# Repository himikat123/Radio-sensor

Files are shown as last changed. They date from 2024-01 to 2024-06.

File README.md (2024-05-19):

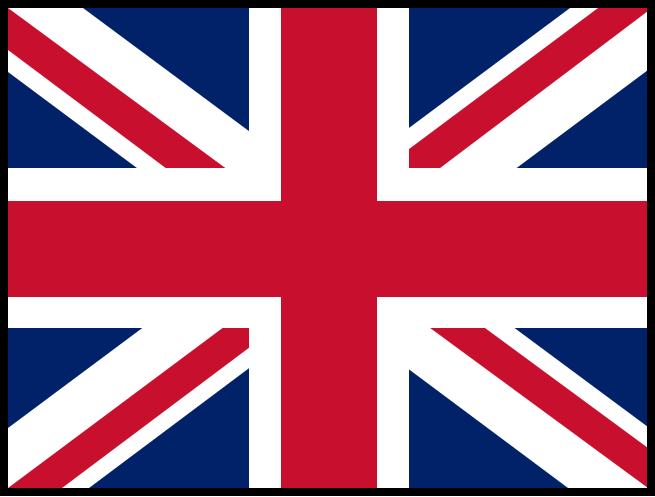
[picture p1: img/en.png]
Read this in english

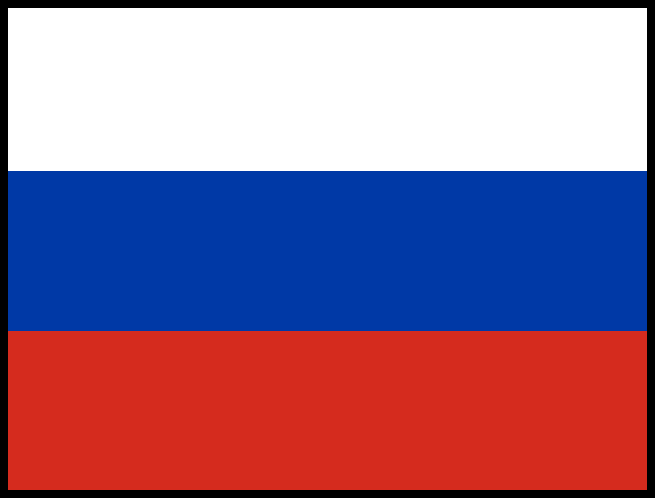
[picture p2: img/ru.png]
Читать на русском


# Radio-sensor

The radio-sensor is designed to work with the <a href="https://github.com/himikat123/Weather-monitor-BIM32">Weather Monitor BIM32.</a> It can work indoors or outdoors. Powered by three AAAA batteries (LR61). Also, the sensor can be powered from a Li-Ion battery, but it is preferable to use batteries, since batteries are not afraid of outdoor frost. 

Currently the radio-sensor supports the following sensors:
  * BME280 - temperature, humidity and atmospheric pressure sensor
  * SHT21 - temperature and humidity sensor
  * DS18B20 - temperature sensor (four such sensors can be connected at once)
  * MAX44009 - ambient light sensor
  * BH1750 - ambient light sensor
  * PZEM-004t - electricity meter (voltage, current, power, energy consumption, network frequency)
  * SenseAir S8 - CO2 sensor

Of course, you don’t need to connect everything from this list, but only those sensors that you need.

As an option, you can add a 4-digit, 7-segment display to the TM1637. Only the temperature can be displayed on the display, from only one temperature sensor. This is an experimental feature, I may remove it in the future.

The radio sensor is based on the Atmega328p microcontroller and the HC-12 radio module. This radio module operates at a frequency from 433.4 to 473.0 MHz and promises an information transmission range of up to 1800 meters.

## Radio-sensor schematic diagramm
The **Radio-sensor** itself can be assembled on the **Arduino Nano** module, or any other module built on the **atmega328p**. In this case, the circuit, assembly and flashing of the **Radio-sensor** will be as simple as possible, but in this form you can forget about the autonomous power supply of the sensor.

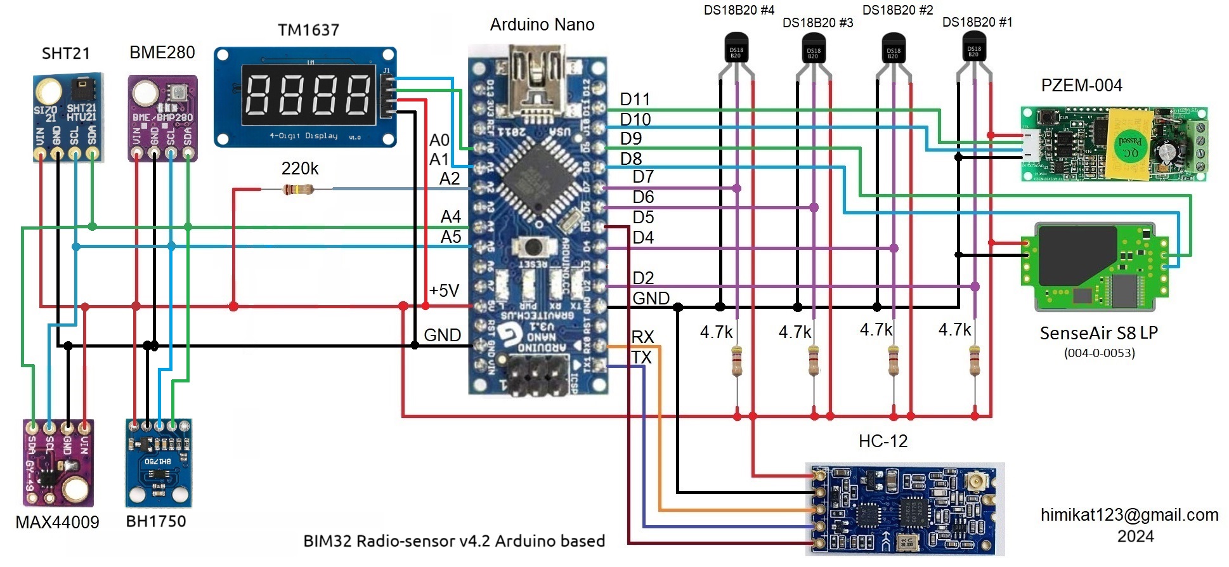
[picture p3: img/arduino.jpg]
weather monitor BIM32 radio-sensor arduino based


Or you can go a more complicated way, assemble the **Radio-sensor** from *SMD-components* and flash it with a programmer. In this case, the **Radio-sensor** will be able to live from three AA batteries for almost a year.

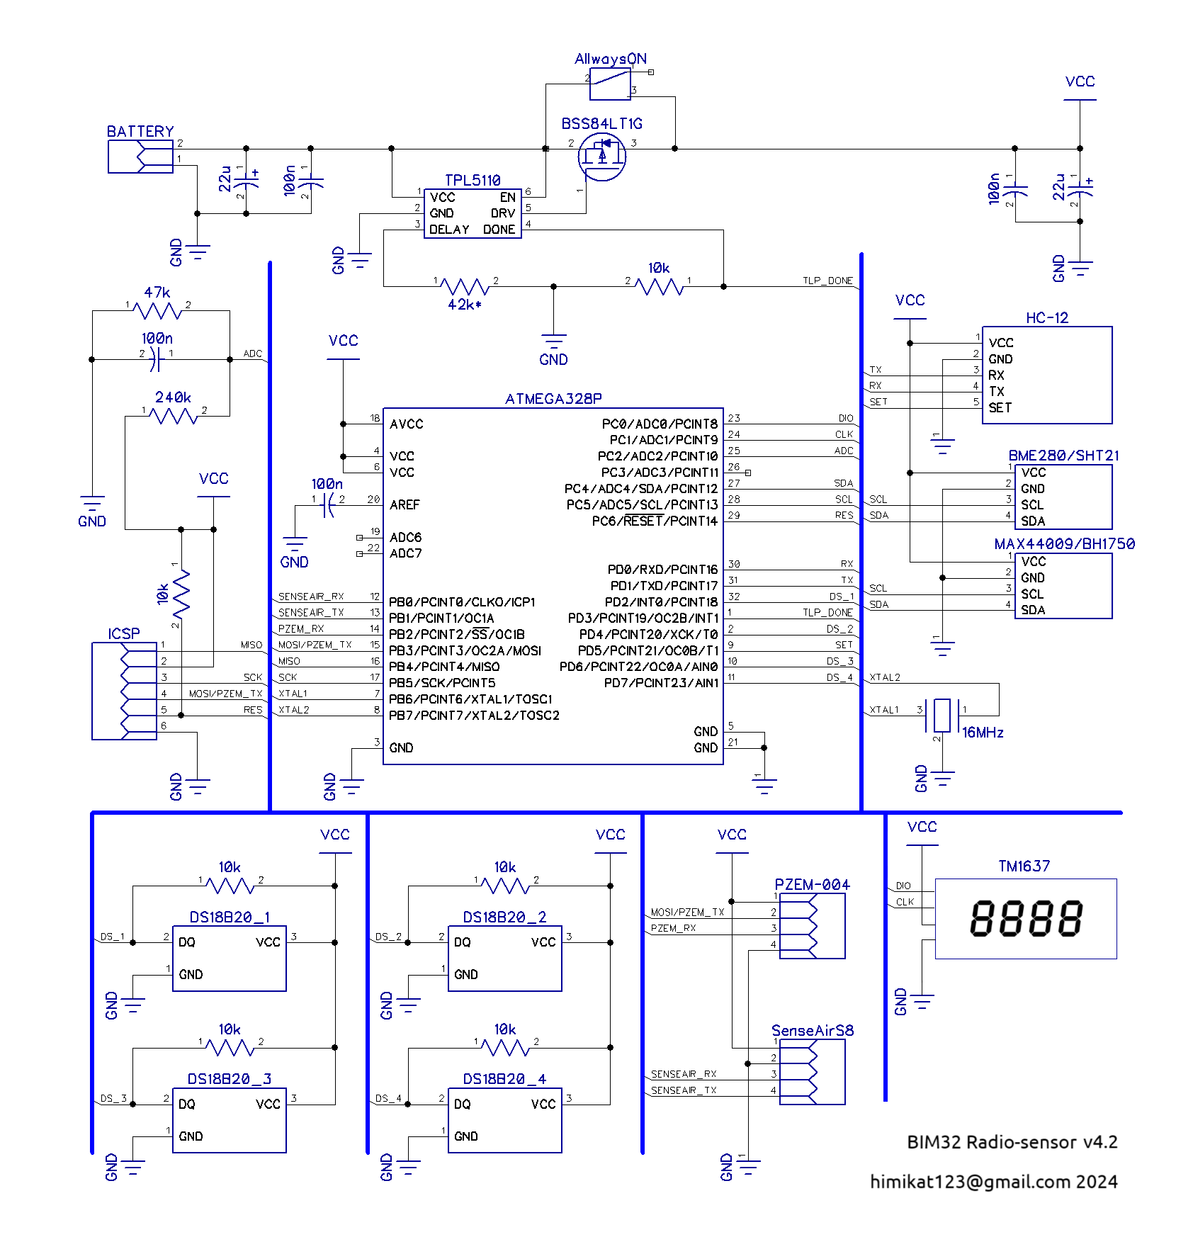
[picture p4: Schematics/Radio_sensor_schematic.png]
weather monitor BIM32 radio-sensor schematic


## Radio-sensor firmware
To flash the **Radio-sensor** you need to open the project in the Arduino IDE, go to the **config.h** tab and uncomment (remove the characters **//** at the beginning of the line) the necessary sensors. If you have 2 radio-sensors - at the end of this file in the line **const int SENSOR_NUMBER = 0;** for the first sensor leave the value **0**, and for the second change **0** to **1**.

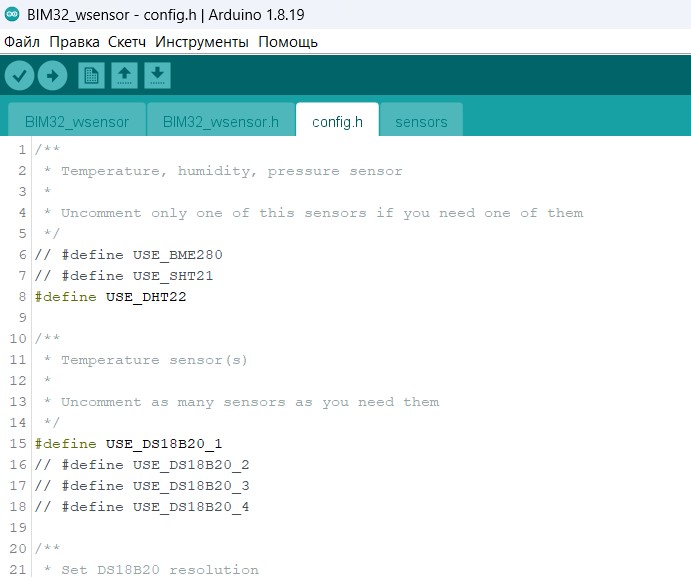
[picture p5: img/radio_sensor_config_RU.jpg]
weather monitor BIM32 radio-sensor config


If your sensor is built on **Arduino module** then just flash it as usual.

And if on ***SMD-components*** - select in the Arduino IDE **Tools** -> **Programmer** -> **Your type of programmer**

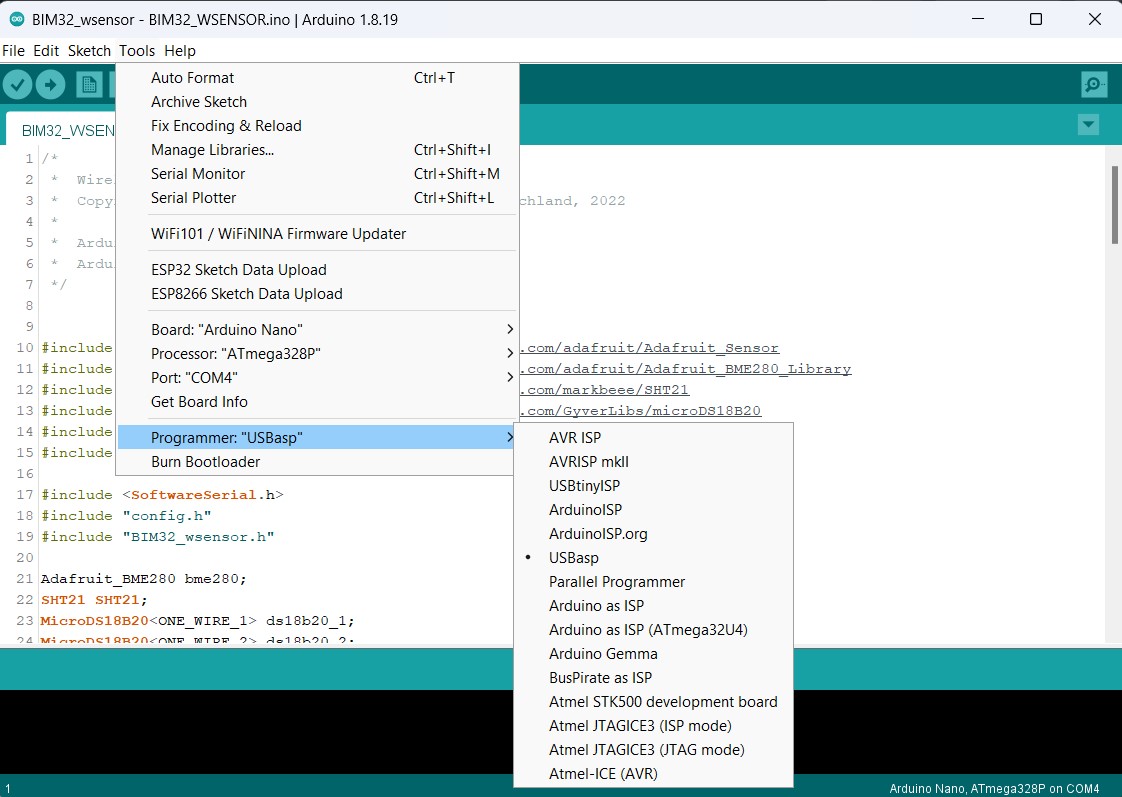
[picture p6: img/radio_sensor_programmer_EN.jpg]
weather monitor BIM32 radio-sensor programmer select


Then click on the menu **Sketch** -> **Download via programmer**

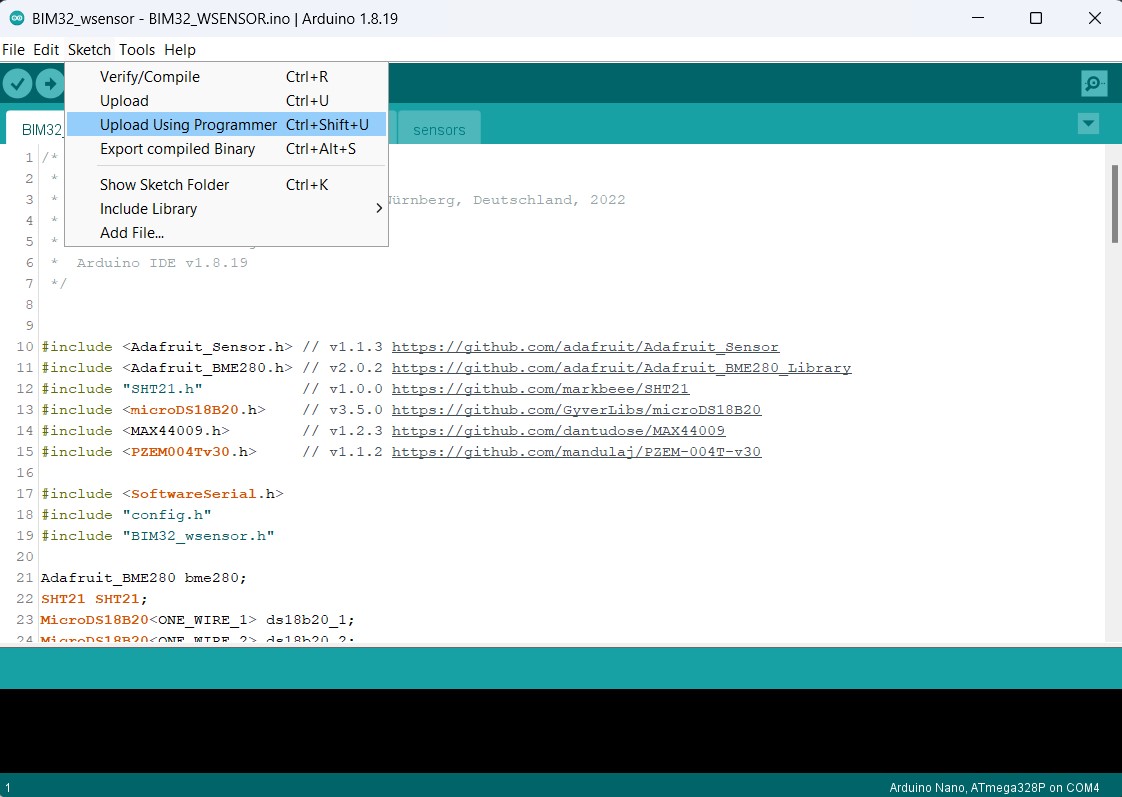
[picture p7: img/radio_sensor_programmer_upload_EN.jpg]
weather monitor BIM32 radio-sensor programmer upload


If Ardino does not have your programmer, select **Sketch** -> **Export binary file** from the menu.

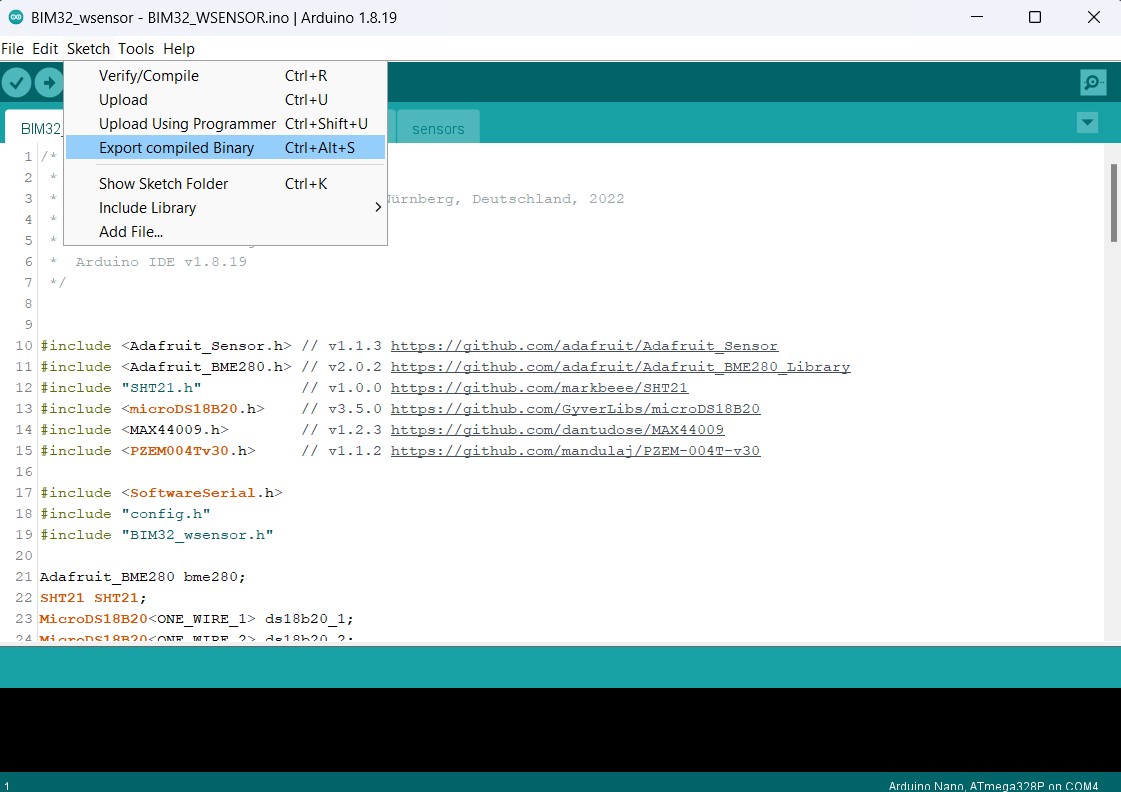
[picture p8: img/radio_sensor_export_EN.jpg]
weather monitor BIM32 radio-sensor export compiled binary


After compilation, two **.hex** files will appear in the project folder, you need the **BIM32_Radio-sensor.ino.eightanaloginputs.hex** one. And you need to flash it into **atmega328p** using a programmer. Set the fuses as in the screenshot below.

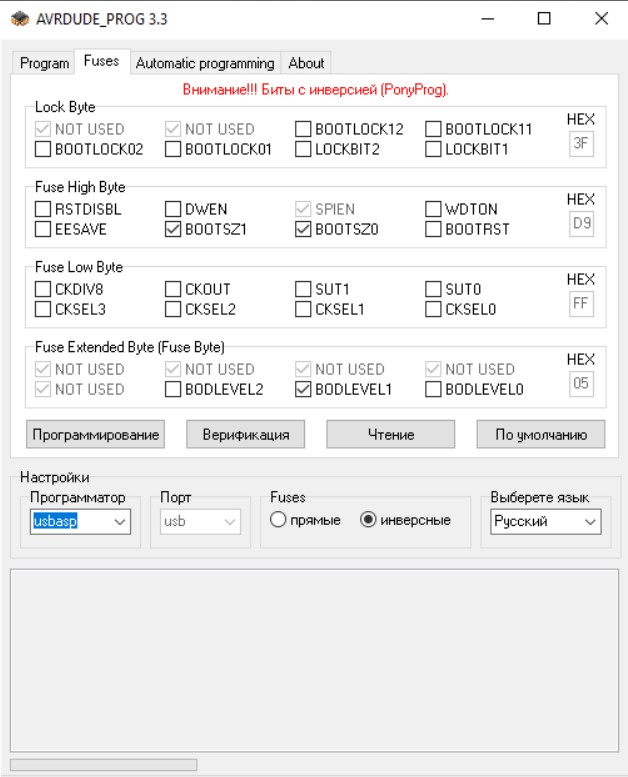
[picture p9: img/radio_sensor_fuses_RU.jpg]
weather monitor BIM32 radio-sensor fuses


# Photo instructions for assembling a 3D printed case

The case is designed for three AAAA (or LR61) batteries. Why them? They are quite small, but quite capacious. You can, of course, use any others, but the case is designed for these. AAAA batteries are not sold in any store and their cost is noticeably higher than AAA or AA. Therefore, it is cheaper and easier to get such batteries from a 9-volt battery 6LR61, it contains as many as six pieces.

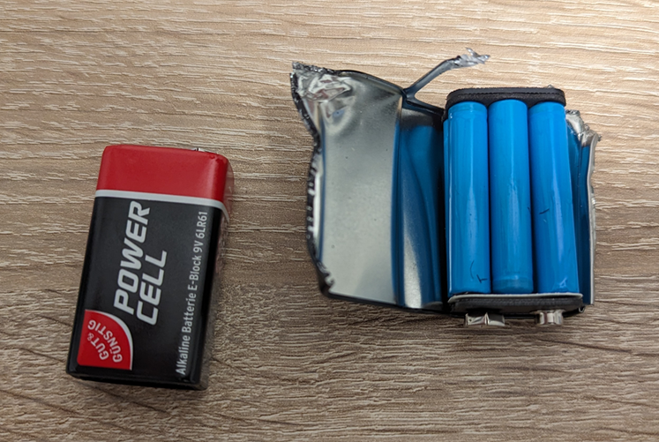
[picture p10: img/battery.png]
weather monitor BIM32 radio-sensor battery


Next, we will need a fully assembled and tested PCB

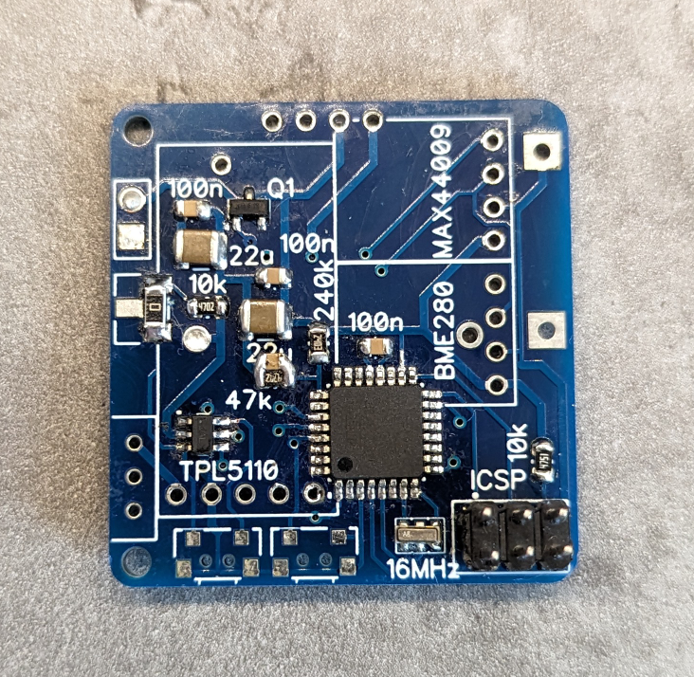
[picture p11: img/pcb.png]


Then, you need to 3D print a battery holder. It is advisable to print it with TPU material, it is like silicone, it can be bent, it is springy and does not break. I made the contacts for the batteries from a wire. There are already special holes for this.

All other parts of the case are printed with ASA material.

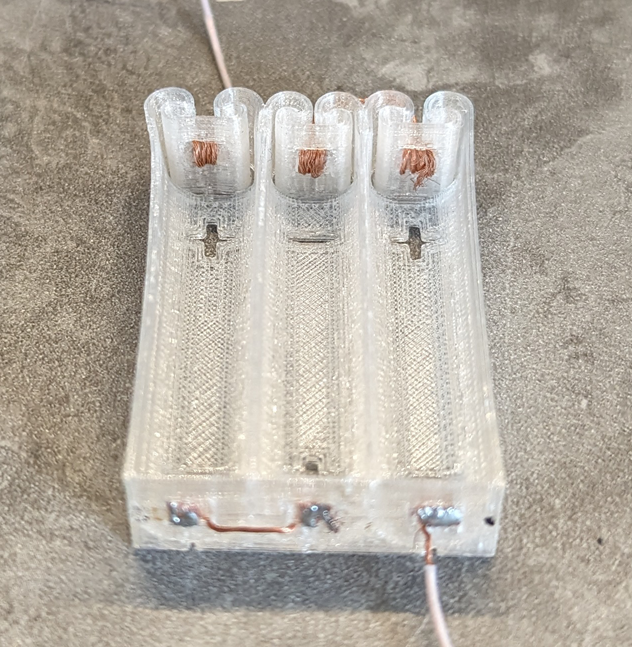
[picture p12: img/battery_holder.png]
weather monitor BIM32 radio-sensor battery holder


Next you need to install insert knurled nuts brass hotmelt

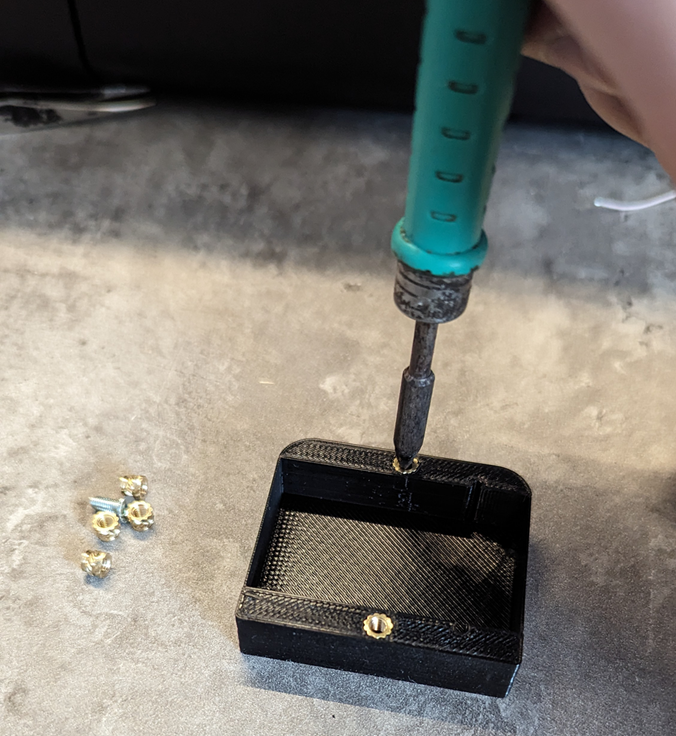
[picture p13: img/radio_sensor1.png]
weather monitor BIM32 radio-sensor brass insert nut


Next, I hope, from the photos it will be clear how to assembly

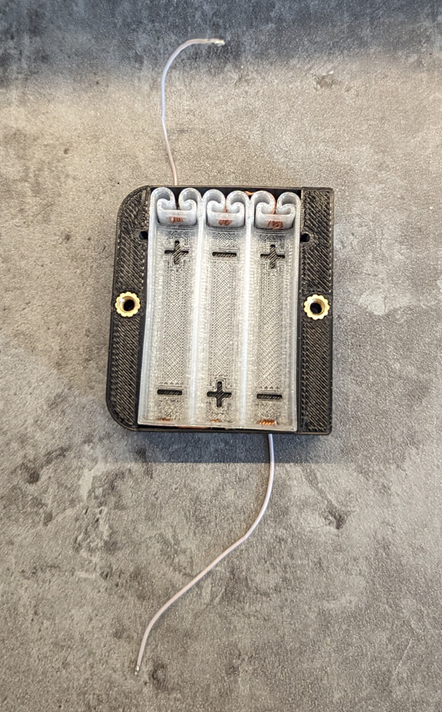
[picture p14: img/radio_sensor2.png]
weather monitor BIM32 radio-sensor battery holder


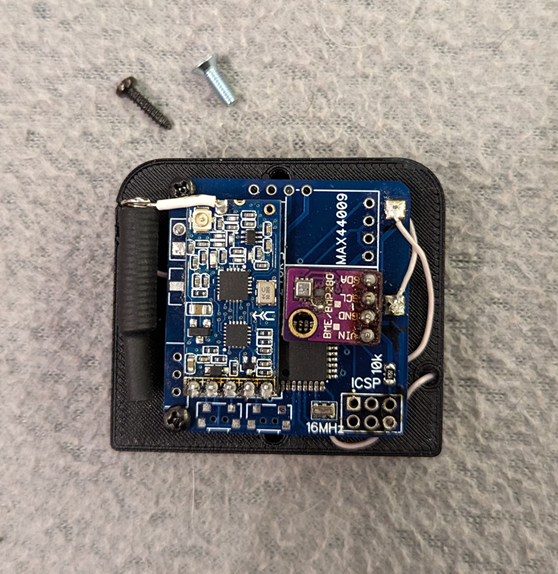
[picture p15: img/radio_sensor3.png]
weather monitor BIM32 radio-sensor pcb


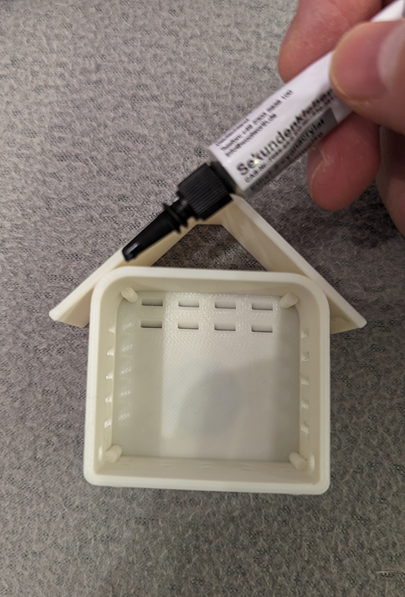
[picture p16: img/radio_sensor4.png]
weather monitor BIM32 radio-sensor glue


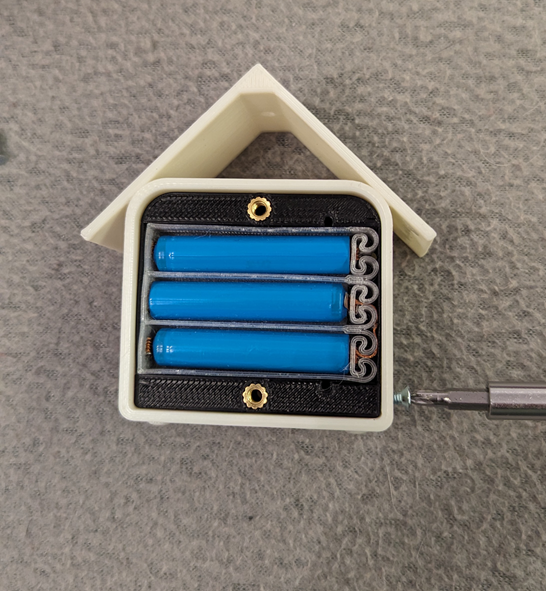
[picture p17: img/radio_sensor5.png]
weather monitor BIM32 radio-sensor assembly


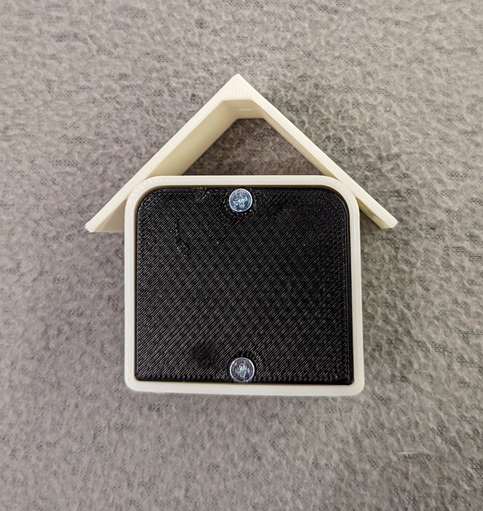
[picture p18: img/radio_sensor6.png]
weather monitor BIM32 radio-sensor enclosure


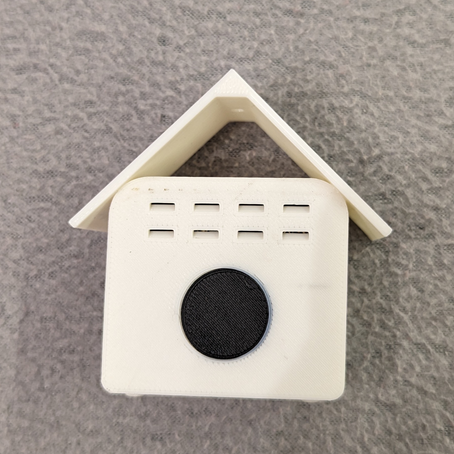
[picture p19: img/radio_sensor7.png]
weather monitor BIM32 radio-sensor enclosure


<hr>

## Do you like the project? Buy me coffee or beer.

<a href="https://www.buymeacoffee.com/himikat123Q">
    Donate
</a>

<a href="https://www.paypal.com/donate/?hosted_button_id=R4QDCRKTC9QA6">
    
</a>

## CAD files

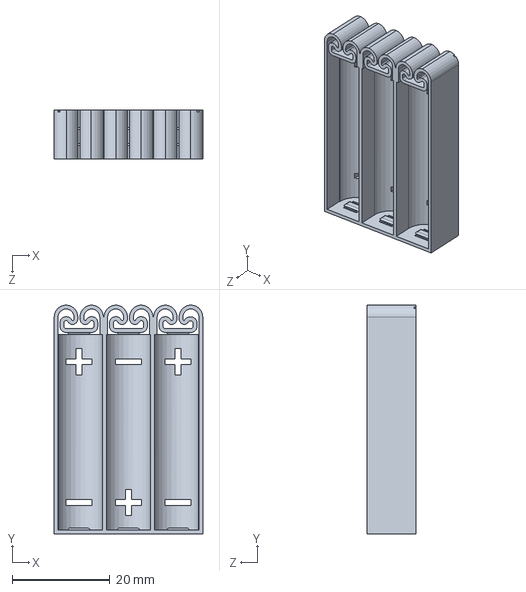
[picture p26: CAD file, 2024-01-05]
Enclosure/Solidworks2023/battery holder/battery_holder.SLDPRT
30.4 x 46.8 x 10.0 mm

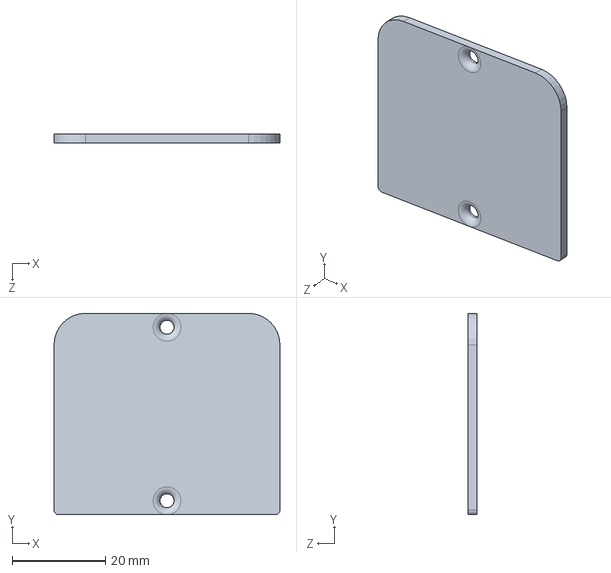
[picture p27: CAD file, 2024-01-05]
Enclosure/Solidworks2023/cover/cover.SLDPRT
48.6 x 43.3 x 2.00 mm

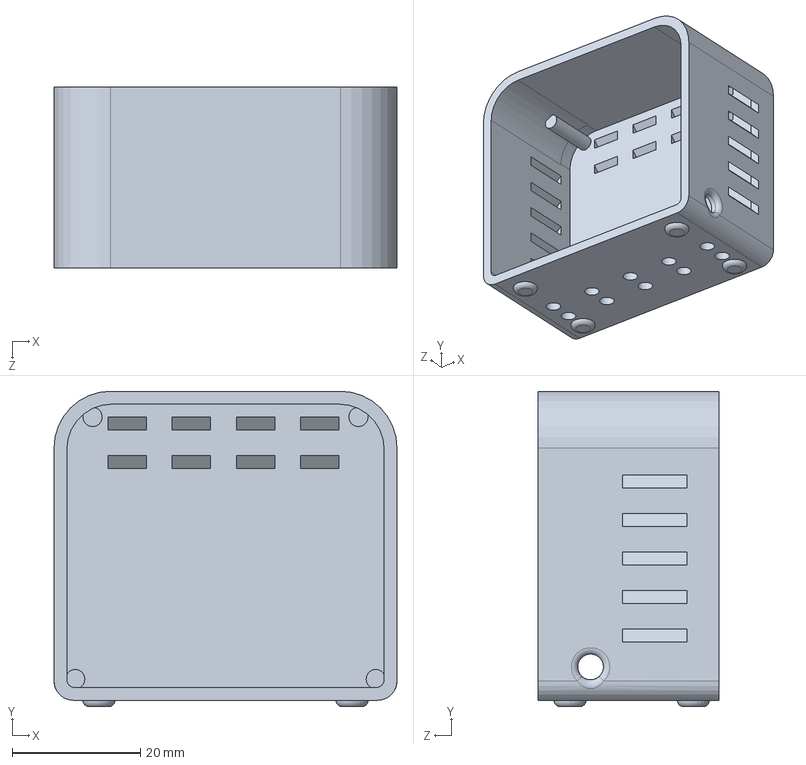
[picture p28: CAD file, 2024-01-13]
Enclosure/Solidworks2023/enclosure/enclosure.SLDPRT
53.4 x 49.1 x 28.2 mm

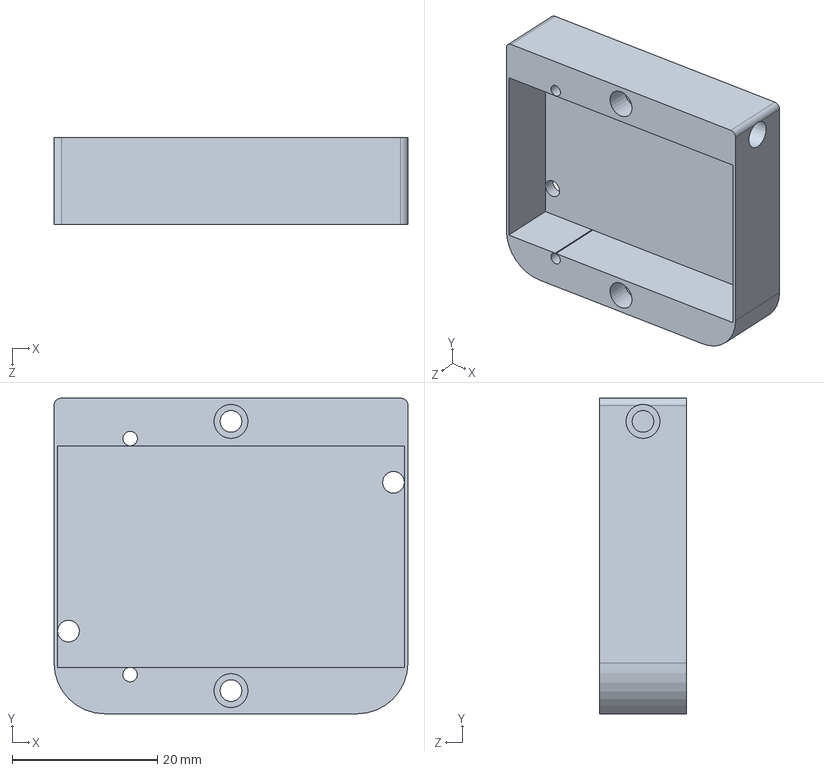
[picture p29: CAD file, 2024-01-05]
Enclosure/Solidworks2023/frame/frame.SLDPRT
48.8 x 43.5 x 12.0 mm

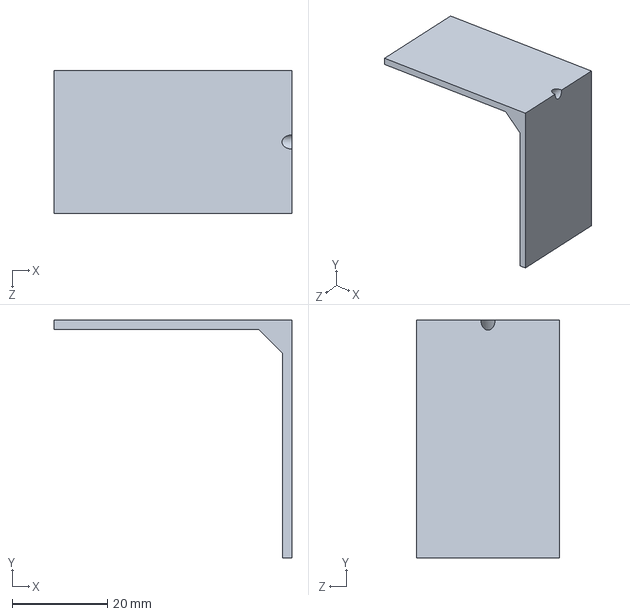
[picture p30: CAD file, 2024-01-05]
Enclosure/Solidworks2023/roof/roof.SLDPRT
50.0 x 50.0 x 30.0 mm

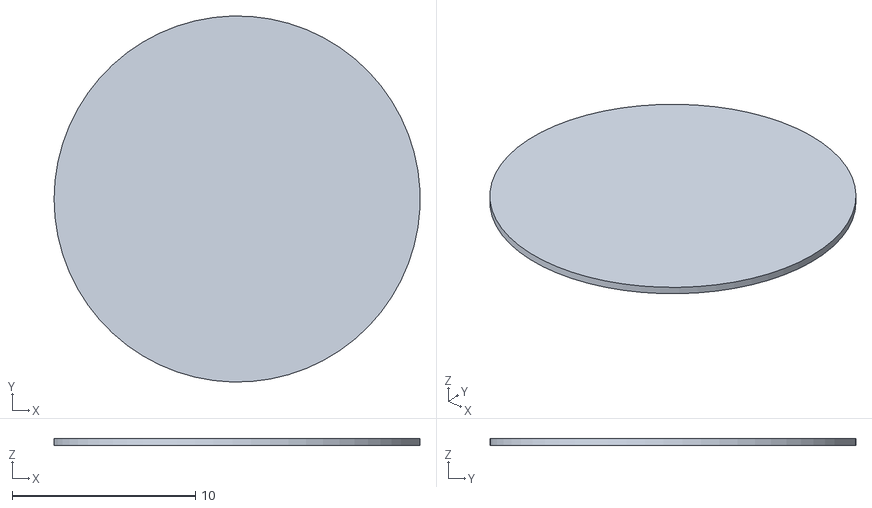
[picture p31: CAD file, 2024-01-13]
Enclosure/STL/enclosure_black.STL
20.0 x 20.0 x 0.4

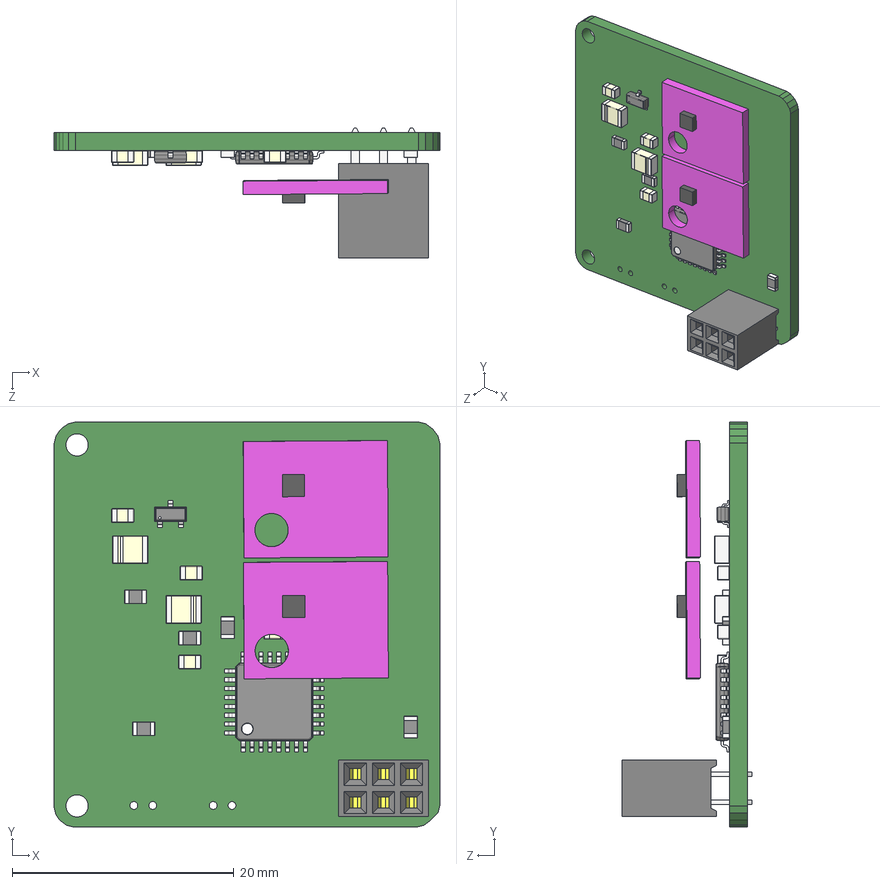
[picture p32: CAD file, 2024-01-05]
Enclosure/Solidworks2023/pcb.step
34.8 x 36.5 x 11.7 mm
Board_pcb
ATMEGA328P-AU
max44009 x 2
CAP_0805_L x 3
CAPP_1210_L x 2
CAP_0805_M
hdrf-2x3t_2.54x2.54_8x5
BVSS84LT1G
RES_0805_M x 5

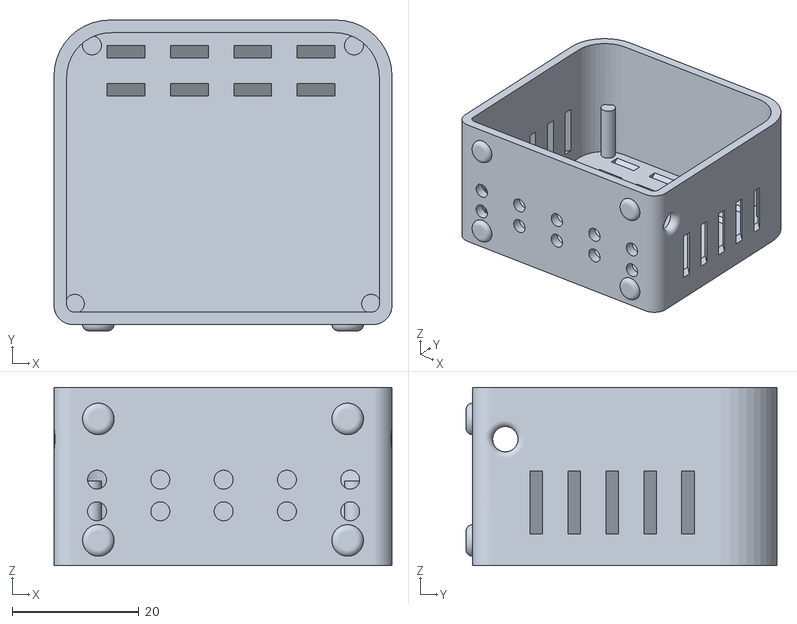
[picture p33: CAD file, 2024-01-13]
Enclosure/STL/enclosure_white.STL
53.4 x 49.1 x 28.2

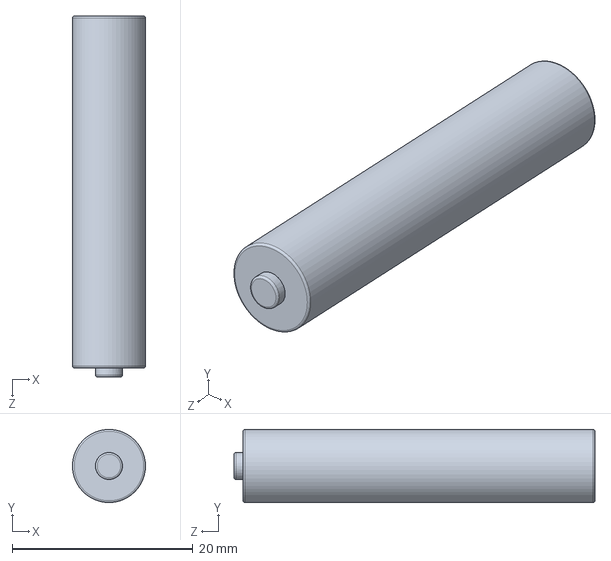
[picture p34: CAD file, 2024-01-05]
Enclosure/Solidworks2023/BatteryAAAA.SLDPRT
8.09 x 8.10 x 40.0 mm

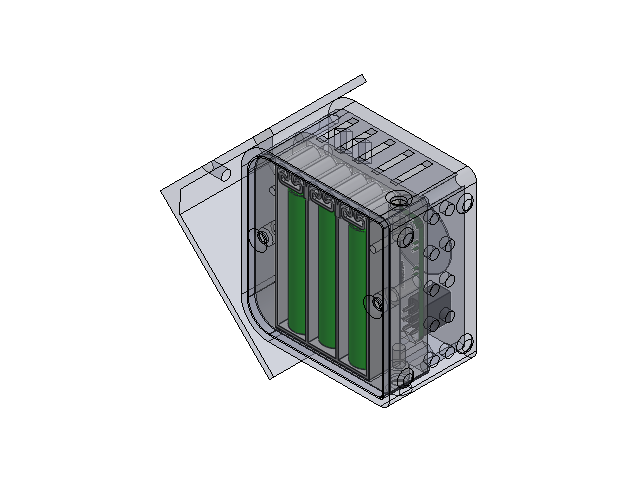
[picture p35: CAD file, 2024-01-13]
Enclosure/Solidworks2023/assembly.SLDASM
battery_holder
BatteryAAAA x 3
Board_pcb.step
ATMEGA328P-AU.step
max44009.step x 2
CAP_0805_L.step x 3
CAPP_1210_L.step x 2
CAP_0805_M.step
hdrf-2x3t_2.54x2.54_8x5.step
BVSS84LT1G.step
RES_0805_M.step x 5
frame
enclosure
roof
cover

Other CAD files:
Enclosure/STL/roof.STL
Enclosure/STL/battery_holder.STL
Enclosure/STL/cover.STL
Enclosure/STL/frame.STL
Enclosure/Solidworks2023/pcb.SLDASM

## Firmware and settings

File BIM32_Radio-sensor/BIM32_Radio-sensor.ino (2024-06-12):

/* 
 *  BIM32 Radio-sensor v4.3
 *  Copyright © himikat123@gmail.com, Nürnberg, Deutschland, 2022-2024
 *
 *  Arduino Nano - ATmega328P
 *  Arduino IDE v1.8.19
 */



#include <Adafruit_Sensor.h> // v1.1.3 https://github.com/adafruit/Adafruit_Sensor
#include <Adafruit_BME280.h> // v2.0.2 https://github.com/adafruit/Adafruit_BME280_Library
#include "SHT21.h"           // v1.0.0 https://github.com/markbeee/SHT21
#include <microDS18B20.h>    // v3.5.0 https://github.com/GyverLibs/microDS18B20
#include <MAX44009.h>        // v1.2.3 https://github.com/dantudose/MAX44009
#include <BH1750.h>          // v1.1.4 https://github.com/claws/BH1750
#include <PZEM004Tv30.h>     // v1.1.2 https://github.com/mandulaj/PZEM-004T-v30
#include <s8_uart.h>         // v1.0.1 https://github.com/jcomas/S8_UART

#include <SoftwareSerial.h>
#include "config.h"
#include "BIM32_Radio-sensor.h"
#include "tm1637.h"

Adafruit_BME280 bme280;
SHT21 SHT21;
MicroDS18B20<ONE_WIRE_1> ds18b20_1;
MicroDS18B20<ONE_WIRE_2> ds18b20_2;
MicroDS18B20<ONE_WIRE_3> ds18b20_3;
MicroDS18B20<ONE_WIRE_4> ds18b20_4;
MAX44009 max44009;
BH1750 bh1750(0x23);
SoftwareSerial pzemSWSerial(PZEM_RX, PZEM_TX);
PZEM004Tv30 pzem(pzemSWSerial);
SoftwareSerial S8_serial(SENSEAIR_RX, SENSEAIR_TX);
S8_UART *sensor_S8;
S8_sensor sensor; 
TM1637 tm1637;

void setup() {
  // Initialization pins to output
  uint8_t pins[] = {12, 13, A0, A1, A3, SET, DONE};
  for(uint8_t i=0; i<sizeof(pins); i++) pinMode(pins[i], OUTPUT);
  
  // Determining the logical state of pins
  digitalWrite(DONE, LOW);
  digitalWrite(SET, HIGH);
  
  // ADC reference voltage setting
  analogReference(INTERNAL);

  // Start serial interface
  Serial.begin(9600);
  while(!Serial);
  
  // Start each software serial port
  pzemSWSerial.begin(9600);
  S8_serial.begin(S8_BAUDRATE);
  sensor_S8 = new S8_UART(S8_serial);
  
  // Sensors initialization
  sensorsInit();

  // Data send
  dataSend();
  delay(30);

  // Power off
  powerOff();
}

void loop() {
  tm1637.print(datas.temp_1); /* Displaying sensor data on display TM1637 */
  
  /* 
   * If the power does not turn off, send data and try to 
   * turn off the power again every 5 seconds
   */
  delay(5000);
  dataSend();
  powerOff();

  if(detected.ds18b20_1) ds18b20_1.requestTemp();
  if(detected.ds18b20_2) ds18b20_2.requestTemp();
  if(detected.ds18b20_3) ds18b20_3.requestTemp();
  if(detected.ds18b20_4) ds18b20_4.requestTemp();
}


/**
 * Power off
 */
void powerOff(void) {
  digitalWrite(DONE, HIGH);
  delay(5);
  digitalWrite(DONE, LOW);
  delay(5);
  digitalWrite(DONE, HIGH);
  delay(10);
}

/**
 * Send data via UART
 */
void dataSend(void) {
  getData();
  uint8_t attempts = 0;

  // wait if another wireless sensor is transmitting data now, 
  // but no more than 5 seconds
  while(Serial.available()) {
    if(attempts++ > 25) break;
    Serial.read();
    delay(200);
  }
  
  // send data
  Serial.print("{");
  Serial.print("\"b\":"); Serial.print(datas.adc);
  Serial.print(",\"num\":\""); Serial.print(SENSOR_NUMBER); Serial.print("\"");
  if(detected.bme280) {
    Serial.print(",\"t\":"); Serial.print(datas.temp);
    Serial.print(",\"h\":"); Serial.print(datas.hum);
    Serial.print(",\"p\":"); Serial.print(datas.pres);
    Serial.print(",\"s\":"); Serial.print("\"BME280\"");
  }
  else if(detected.sht21) {
    Serial.print(",\"t\":"); Serial.print(datas.temp);
    Serial.print(",\"h\":"); Serial.print(datas.hum);
    Serial.print(",\"s\":"); Serial.print("\"SHT21\"");
  }
  if(detected.max44009) {
    Serial.print(",\"l\":"); Serial.print(datas.light);
    Serial.print(",\"a\":"); Serial.print("\"MAX44009\"");
  }
  else if(detected.bh1750) {
    Serial.print(",\"l\":"); Serial.print(datas.light);
    Serial.print(",\"a\":"); Serial.print("\"BH1750\"");
  }
  #ifdef USE_DS18B20_1
    Serial.print(",\"ds\":["); Serial.print(datas.temp_1); 
    Serial.print(","); Serial.print(datas.temp_2);
    Serial.print(","); Serial.print(datas.temp_3);
    Serial.print(","); Serial.print(datas.temp_4);
    Serial.print("]");
  #endif
  #ifdef USE_PZEM_004T
    Serial.print(",\"pzem\":[");
    Serial.print(datas.voltage, 1); Serial.print(",");
    Serial.print(datas.current, 3); Serial.print(",");
    Serial.print(datas.power, 1); Serial.print(",");
    Serial.print(datas.energy, 2); Serial.print(",");
    Serial.print(datas.frequency, 1); Serial.print(",");
    Serial.print(datas.pf, 2);
    Serial.print("]");
  #endif
  if(detected.s8) {
    Serial.print(",\"s8\":"); Serial.print(datas.co2);
  }
  Serial.println("}");
  Serial.flush();
  #ifdef USE_DS18B20_1
    delay(50);
  #endif
}

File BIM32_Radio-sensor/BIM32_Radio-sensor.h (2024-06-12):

#define BAT           A2 // ADC battery voltage pin (PC2 -> pin #25)
#define SET            5 // HC-12 wireless module SET pin (PD5 -> pin #9)
#define DONE           3 // TPL5110 DONE pin (PD3 -> pin #1)
#define ONE_WIRE_1     2 // DS18B20 #1 bus pin (PD2 -> pin #32)
#define ONE_WIRE_2     4 // DS18B20 #2 bus pin (PD4 -> pin #2)
#define ONE_WIRE_3     6 // DS18B20 #3 bus pin (PD6 -> pin #18) 
#define ONE_WIRE_4     7 // DS18B20 #4 bus pin (PD7 -> pin #11)
#define SENSEAIR_RX    8 // SENSEAIR_S8 UART TX pin (PB0 -> pin #12)
#define SENSEAIR_TX    9 // SENSEAIR_S8 UART RX pin (PB1 -> pin #13)
#define PZEM_RX       10 // PZEM_004T UART TX pin (PB2 -> pin #14)
#define PZEM_TX       11 // PZEM_004T UART RX pin (PB3 -> pin #15)
#define TM1637_DIO    A0 // TM1637 display DIO pin (PC0 -> pin #23)
#define TM1637_CLK    A1 // TM1637 display CLK pin (PC1 -> pin #24)

struct {
  bool bme280 = false;
  bool sht21 = false;
  bool ds18b20_1 = false;
  bool ds18b20_2 = false;
  bool ds18b20_3 = false;
  bool ds18b20_4 = false;
  bool max44009 = false;
  bool bh1750 = false;
  bool s8 = false;
} detected;

struct {
  float temp = 404.0;
  float temp_1 = 404.0;
  float temp_2 = 404.0;
  float temp_3 = 404.0;
  float temp_4 = 404.0;
  float hum = 202.0;
  float pres = 4040.0;
  float light = -1.0;
  uint16_t adc = 0;
  float voltage = -1.0;
  float current = -1.0;
  float power = -1.0;
  float energy = -1.0;
  float frequency = -1.0;
  float pf = -1.0;
  uint16_t co2 = 0;
} datas;

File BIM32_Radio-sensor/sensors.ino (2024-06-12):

/**
 * Sensors initialization
 */
void sensorsInit(void) {
  
  //BME280 initialization
  #ifdef USE_BME280
    if(bme280.begin(0x77, &Wire)) detected.bme280 = true;
    else if(bme280.begin(0x76, &Wire)) detected.bme280 = true;
  #endif

  //SHT21 initialization
  #ifdef USE_SHT21
    SHT21.begin();
    Wire.beginTransmission(SHT21_ADDRESS);
    Wire.write(0xE7);
    Wire.endTransmission();
    delay(50);
    Wire.requestFrom(SHT21_ADDRESS, 1);
    if(Wire.available() == 1) {
      Wire.read();
      detected.sht21 = true;
    }
  #endif

  uint8_t ds_address[8];
  //DS18B20 initialization
  #ifdef USE_DS18B20_1
    if(ds18b20_1.readAddress(ds_address)) {
      detected.ds18b20_1 = true;
      ds18b20_1.setResolution(DS18B20_RESOLUTION);
      ds18b20_1.requestTemp();
    }
  #endif
  #ifdef USE_DS18B20_2
    if(ds18b20_2.readAddress(ds_address)) {
      detected.ds18b20_2 = true;
      ds18b20_2.setResolution(DS18B20_RESOLUTION);
      ds18b20_2.requestTemp();
    }
  #endif
  #ifdef USE_DS18B20_3
    if(ds18b20_3.readAddress(ds_address)) {
      detected.ds18b20_3 = true;
      ds18b20_3.setResolution(DS18B20_RESOLUTION);
      ds18b20_3.requestTemp();
    }
  #endif
  #ifdef USE_DS18B20_4
    if(ds18b20_4.readAddress(ds_address)) {
      detected.ds18b20_4 = true;
      ds18b20_4.setResolution(DS18B20_RESOLUTION);
      ds18b20_4.requestTemp();
    }
  #endif
  
  //MAX44009 initialization
  #ifdef USE_MAX44009
    if(!max44009.begin()) detected.max44009 = true;
  #endif

  //BH1750 initialization
  #ifdef USE_BH1750
    if(bh1750.begin(BH1750::CONTINUOUS_HIGH_RES_MODE_2)) detected.bh1750 = true;
  #endif

   //S8 initialization
  #ifdef USE_S8
    sensor_S8->get_firmware_version(sensor.firm_version);
    int len = strlen(sensor.firm_version);
    if(len) detected.s8 = true;
  #endif
}

/**
 * Get sensor data
 */
void getData(void) {
  
  //BME280 read
  #ifdef USE_BME280
    if(detected.bme280) {
      datas.temp = bme280.readTemperature();
      datas.hum = bme280.readHumidity();
      datas.pres = bme280.readPressure() / 100.0F;
    }
  #endif

  //SHT21 read
  #ifdef USE_SHT21
    if(detected.sht21) {
      datas.temp = SHT21.getTemperature();
      datas.hum = SHT21.getHumidity();
    }
  #endif

  //DS18B20 read
  #ifdef USE_DS18B20_1
    if(DS18B20_RESOLUTION == 9) delay(94);
    if(DS18B20_RESOLUTION == 10) delay(188);
    if(DS18B20_RESOLUTION == 11) delay(375);
    if(DS18B20_RESOLUTION == 12) delay(750);
    if(detected.ds18b20_1) datas.temp_1 = ds18b20_1.getTemp();

    #ifdef USE_DS18B20_2
      if(detected.ds18b20_2) datas.temp_2 = ds18b20_2.getTemp();

      #ifdef USE_DS18B20_3
        if(detected.ds18b20_3) datas.temp_3 = ds18b20_3.getTemp();

        #ifdef USE_DS18B20_4
          if(detected.ds18b20_4) datas.temp_4 = ds18b20_4.getTemp();
        #endif
      #endif
    #endif
  #endif
  
  //MAX44009 read
  #ifdef USE_MAX44009
    if(detected.max44009) datas.light = max44009.get_lux();
  #endif

  //BH1750 read
  #ifdef USE_BH1750
    if(detected.bh1750) datas.light = bh1750.readLightLevel();
  #endif
    
  //Battery voltage read
  datas.adc = analogRead(BAT);

  //PZEM-004T read
  #ifdef USE_PZEM_004T
    float voltage = pzem.voltage();
    if(!isnan(voltage)) datas.voltage = voltage;
    else datas.voltage = -1.0;
    float current = pzem.current();
    if(!isnan(current)) datas.current = current;
    else datas.current = -1.0;
    float power = pzem.power();
    if(!isnan(power)) datas.power = power;
    else datas.power = -1.0;
    float energy = pzem.energy();
    if(!isnan(energy)) datas.energy = energy;
    else datas.energy = -1.0;
    float frequency = pzem.frequency();
    if(!isnan(frequency)) datas.frequency = frequency;
    else datas.frequency = -1.0;
    float pf = pzem.pf();
    if(!isnan(pf)) datas.pf = pf;
    else datas.pf = -1.0;
  #endif

  //S8 read
  #ifdef USE_S8
    if(detected.s8) datas.co2 = sensor_S8->get_co2();
  #endif
}

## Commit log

2024-01-13 depth fine tune
    [assembly.SLDASM, enclosure.SLDPRT, enclosure_black.STL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]
2024-01-13 add enclosure photos
2024-02-04 add BH1750 ambient light sensor support
2024-06-12 fixed unstable transmission when using ds18b20
    [BIM32_Radio-sensor.ino]
2024-06-12 corrected the sequence of numbers
    [tm1637.h]
